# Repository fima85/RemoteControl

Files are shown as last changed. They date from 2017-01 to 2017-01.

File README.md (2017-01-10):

# RemoteControl
This application allows the user to control an electric whell chair via bluetooth.

Included, you can find the 3D model for the joystick adapter and instructions on how to print it and the schematic for the electronic circuit (and a shopping list!).
Our original usecase was for a disabled young man, who wanted to be able to send his chair away from his bed when visitors came, and call it back once they left.

Turns out that when life takes some independence from you, the best think you can do for someone, is give it back to him.

If YOU build it, it WILL come!

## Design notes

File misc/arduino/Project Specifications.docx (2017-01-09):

Project Specifications: Chair Call

System Requirements:

Close Range Remote Control System for controlling wheelchair in a room.

System should be removable. Simple attachment and detachment.

Nurse will place the device upon the wheelchair.

Parts:

Main Frame:

A main unit will fit upon the joystick. The main unit has holes for wiring, and 3* M3 holes for securing the servo holder to the Main Frame.

The frame is built to fit tightly in 3 directions around the joystick housing.

Servo Holder:

The servo holder will attach to the main unit, with M3 bolts.

The servo holder is built for two standard size servo motors

It includes a switch and a charge port.

Ring:

A ring will attach to the joystick, padded with rubber for a tight fit over the joystick. Internal Diameter is set to be joystick diameter + 4mm to allow padding. Prototype ring was cut from 3mm acrylic in a laser cutter. Similar results where achieved in 3d printing. The sheathing of a DVI cable was cut off, and split down the bottom. The sheathing was wrapped around the inside of the ring, and fastened with sewing string.

Connecting Rods:

Circuit:

Arduino Nano

Bluetooth Module

2*100KΩ Resistors

Mechanical Parts:

3* M3x30 Bolt

3* M3 Nuts

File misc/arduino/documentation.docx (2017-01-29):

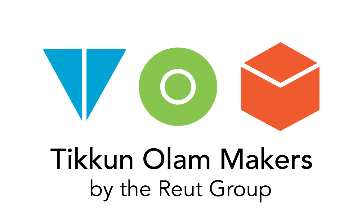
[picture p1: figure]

# Build Instructions: Chair Call

Allowing remote control over a wheel chair via Bluetooth

Developed by: Idan Timsit, Natan Vinshtok Melnik, Maor Farid, Rafael Borenstein, Effi Hagai, Fima Autenshlus, Hila Boral, Mati Gurten, Yonatan Schachter

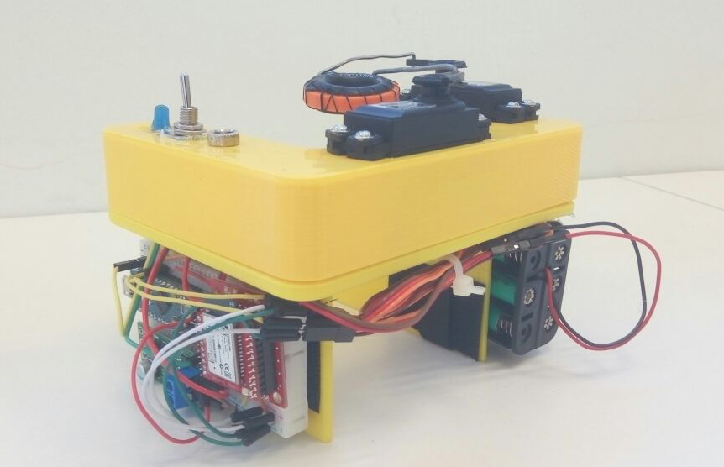
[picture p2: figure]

Approximate Cost: Insert cost

Time Required: 6 hours

# General Warnings and Cautions

- Read through entire manual before attempting to build this device.
- Do not attempt a step if you are unsure of what you are doing. Certain steps in this manual require experience with fabrication tools.

# User Assistance

For any questions regarding the assembly, operation, or specifications of this device, please visit https://github.com/fima85/remotecontrol

# Icon Glossary

The following icons may be used throughout this manual—each with its own purpose.

- Caution: The caution icon is used to signify whenever someone attempting the procedure may injure themselves or damage their equipment.
- Note: The note icon is used to signify useful bits of information that complement the instructions.
- Reminder: The reminder icon is used to provide information for after the procedure is completed, such as tips for disassembly.

# Purpose of Device:

This device allows a wheel chair user to remotely control his wheelchair. It can be very useful for some cases. For example, when the user has visitors, he might want to move the chair away from his bed.

# Physical Description:

The device consists of three parts:

1) Software: The user uses the controls in the custom app that we built. The app sends the commands via Bluetooth to the Electronics.
2) Electronics: A Bluetooth module receives the commands sent by the user. It then moves the servos accordingly.
3) Mechanical: the servos are mechanically connected to the original joystick of the wheelchair.

History of Development:

This device was developed at TOM:IL 2017.

# Bill of Materials

# Tools Required:

- 3D printer
- A computer with the Arduino software and drivers
- Hot glue
- Screwdrivers
- Soldering iron
- Pliers

# Parts Inventory:

- Click here to enter text.
- Click here to enter text.
- Click here to enter text.

[Insert image of parts]

# Subassembly 1: Title of Subassembly

[Insert image of subassembly]

Approximate Cost: Insert cost

Time Required: Insert time

# Step Number

## Parts and Tools Used In This Step:

[Insert image(s) for step]

- Click here to enter text.
- Click here to enter text.
- Click here to enter text.

[Insert image of parts and tools used]

## Instructions

- Click here to enter text.
- Click here to enter text.
- Click here to enter text.
- Click here to enter text.
- Click here to enter text.
- Click here to enter text.
- Click here to enter text.

# Step Number

## Parts and Tools Used In This Step:

[Insert image(s) for step]

- Click here to enter text.
- Click here to enter text.
- Click here to enter text.

[Insert image of parts and tools used]

## Instructions

- Click here to enter text.
- Click here to enter text.
- Click here to enter text.
- Click here to enter text.
- Click here to enter text.
- Click here to enter text.
- Click here to enter text.

# Step Number

## Parts and Tools Used In This Step:

[Insert image(s) for step]

- Click here to enter text.
- Click here to enter text.
- Click here to enter text.

[Insert image of parts and tools used]

## Instructions

- Click here to enter text.
- Click here to enter text.
- Click here to enter text.
- Click here to enter text.
- Click here to enter text.
- Click here to enter text.
- Click here to enter text.

© Tikkun Olam Makers—<<License>>www.tomglobal.orgPage 4

© Tikkun Olam Makers—<<License>>www.tomglobal.orgPage 5

© Tikkun Olam Makers—<<License>>www.tomglobal.orgPage 9

Build Instructions: Chair Call Last revised: 1/10/2017

Build Instructions: Click here to enter text. Last revised: Click here to enter a date.

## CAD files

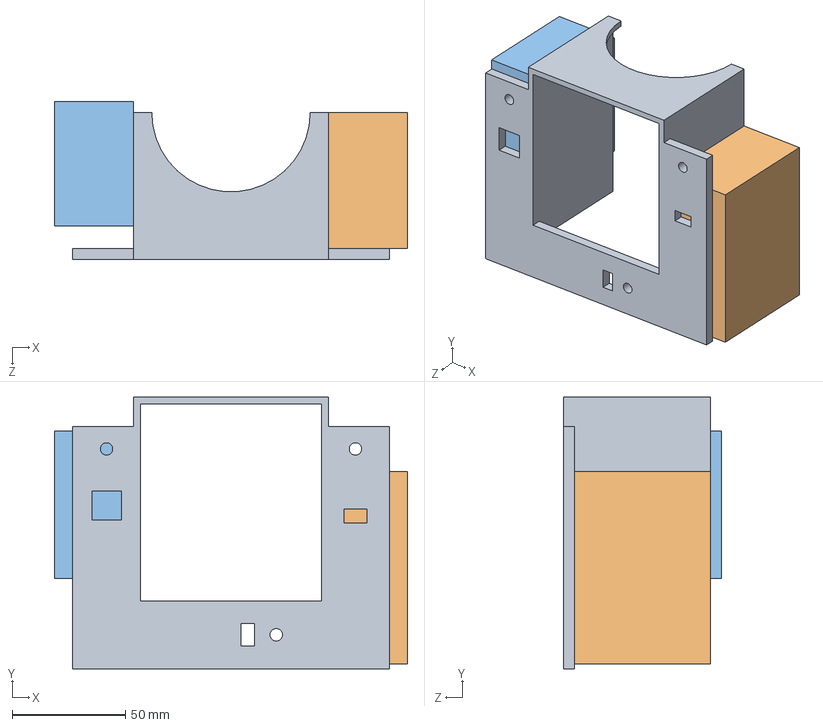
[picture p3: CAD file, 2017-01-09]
misc/ACS Joystick sketch/Assemblyjan8th925PM.SLDASM
156.0 x 120.0 x 70.0 mm
frameRev3
electronics
bataries

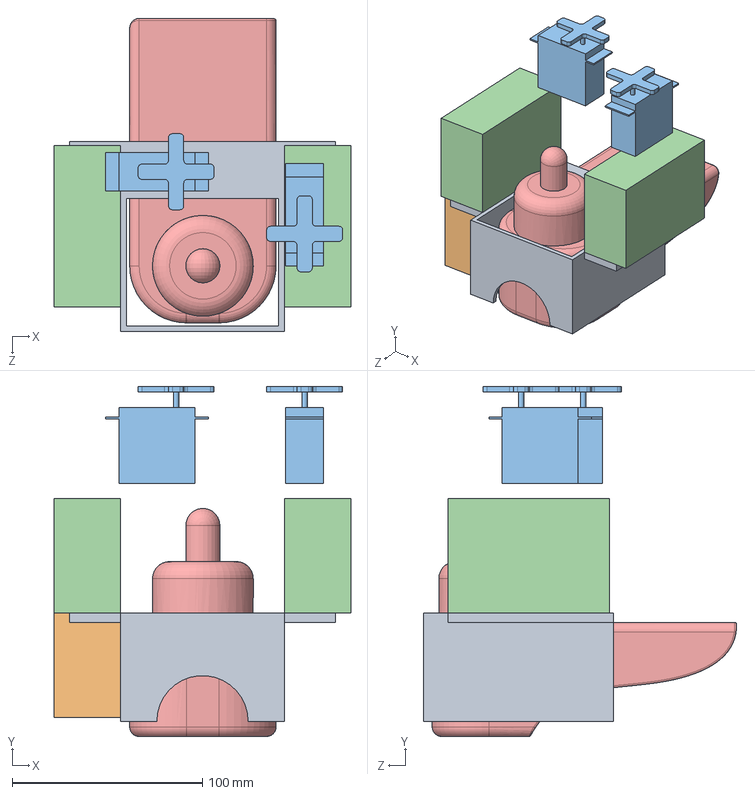
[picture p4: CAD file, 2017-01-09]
misc/ACS Joystick sketch/device_asm.SLDASM
156.0 x 184.0 x 164.6 mm
frameRev2
bataries
shoshana x 2
electronics x 2
Joystick

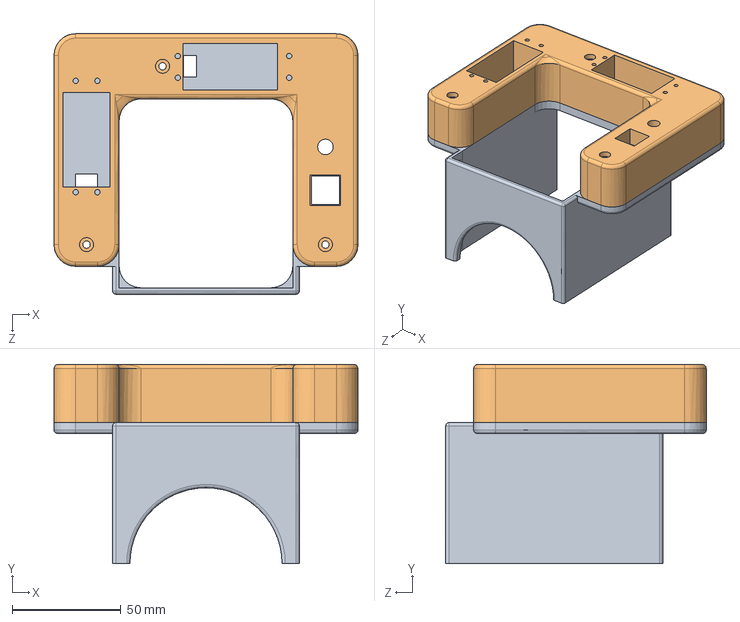
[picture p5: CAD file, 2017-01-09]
misc/ACS Joystick sketch/Assemblyjan9th103PM.SLDASM
140.0 x 91.8 x 120.0 mm
frameRev4
ServoHolderRev4

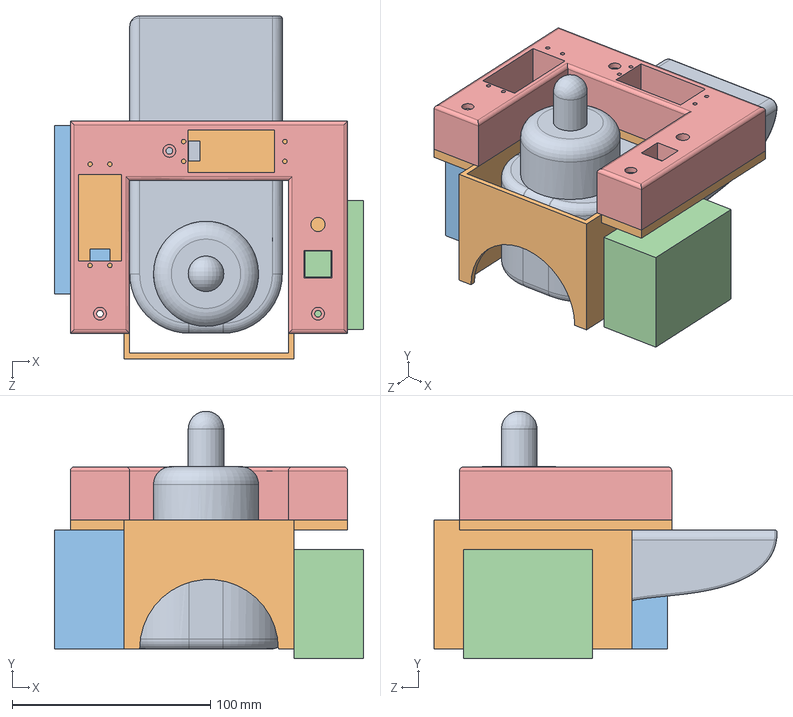
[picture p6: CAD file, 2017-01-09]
misc/ACS Joystick sketch/total_asm2.SLDASM
156.0 x 124.9 x 173.1 mm
Joystick
frameRev3
electronics
bataries
ServoHolderRev3

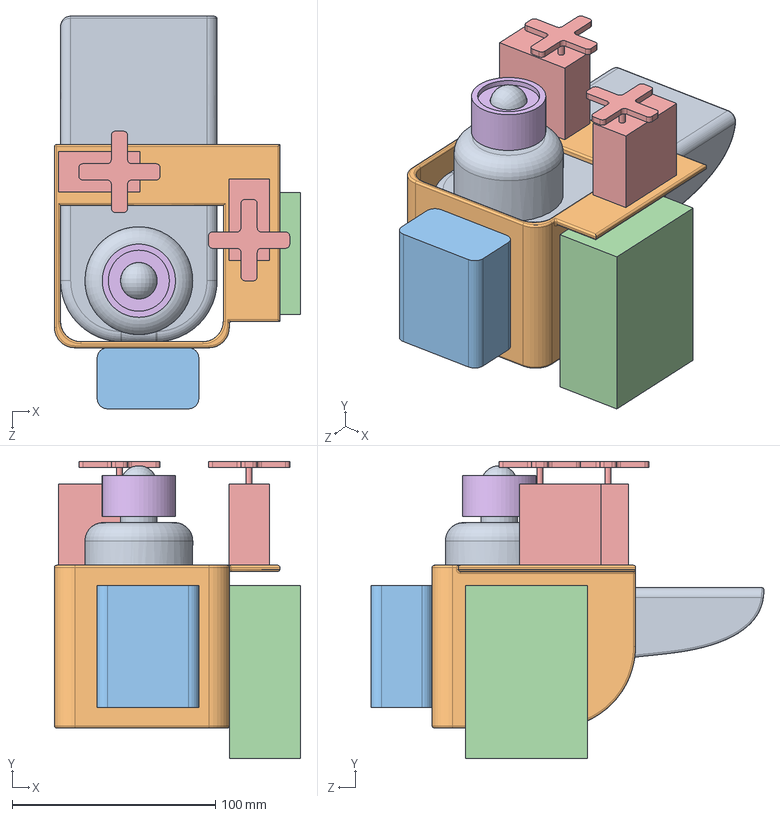
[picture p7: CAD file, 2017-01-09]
misc/ACS Joystick sketch/total_asm.SLDASM
121.0 x 146.0 x 193.1 mm
Joystick
frameRev2
bataries
electronics
shoshana x 2
gumi

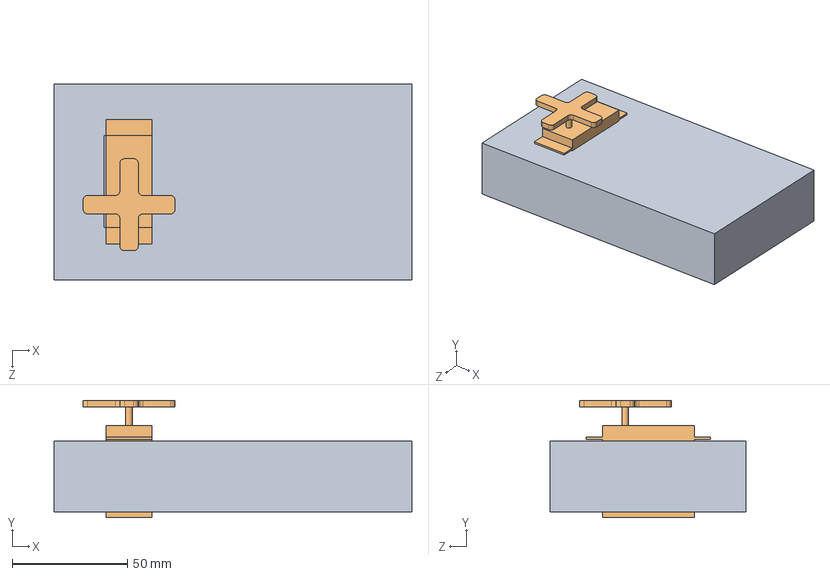
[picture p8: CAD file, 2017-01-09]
misc/ACS Joystick sketch/Assem1.SLDASM
155.5 x 51.0 x 85.3 mm
platform_test
shoshana

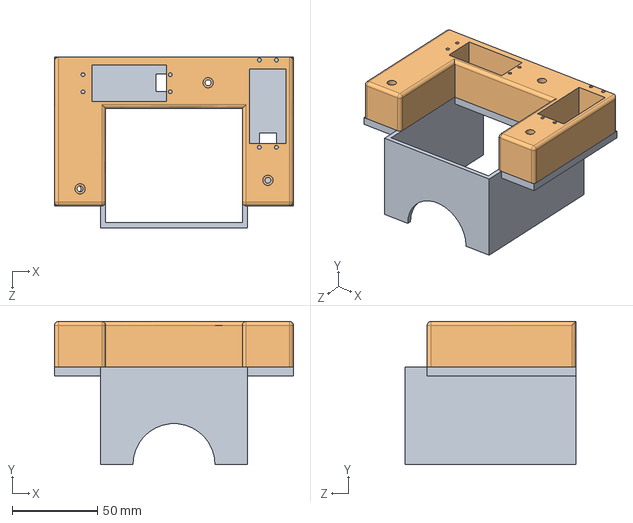
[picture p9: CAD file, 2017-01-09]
misc/ACS Joystick sketch/Assemblyjan8th743PM.SLDASM
140.0 x 83.8 x 100.0 mm
frameRev2
ServoHolderRev2

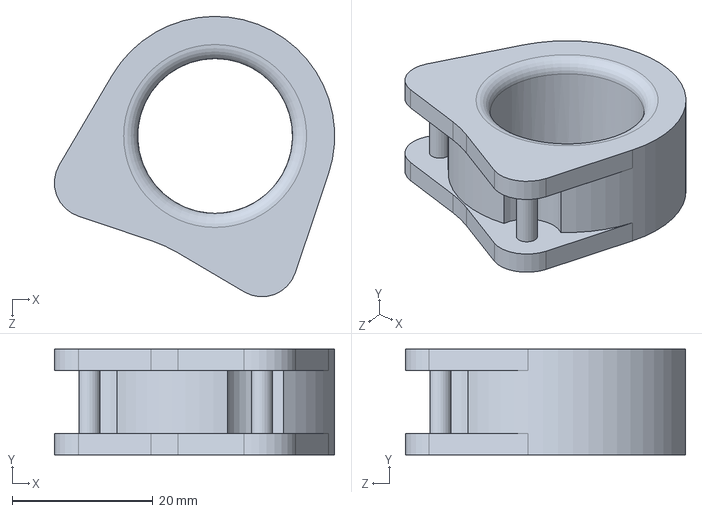
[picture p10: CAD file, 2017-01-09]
misc/ACS Joystick sketch/RingTest.SLDPRT
39.8 x 15.0 x 39.8 mm

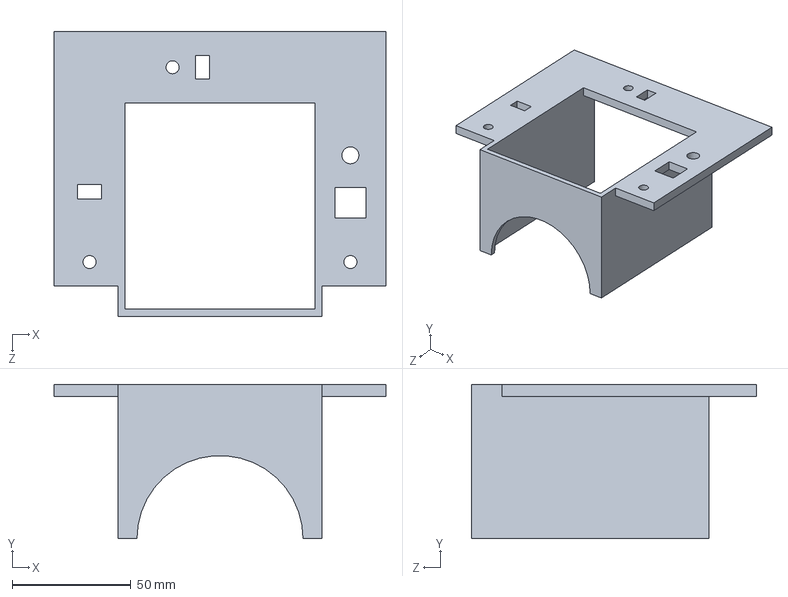
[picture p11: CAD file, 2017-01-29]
misc/arduino/frameRev4.SLDPRT
140.0 x 65.0 x 120.0 mm

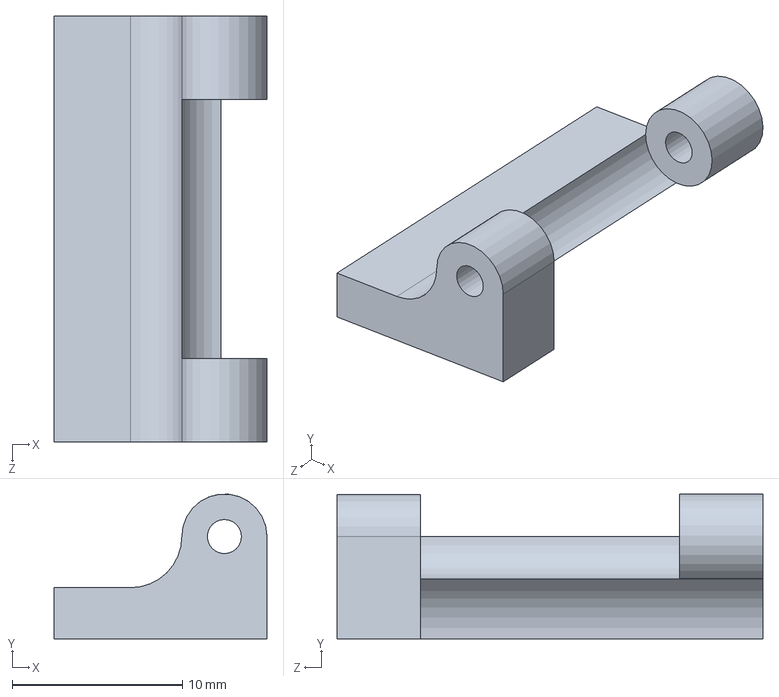
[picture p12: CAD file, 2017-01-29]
misc/arduino/battery_hinge.SLDPRT
12.5 x 8.49 x 25.0 mm

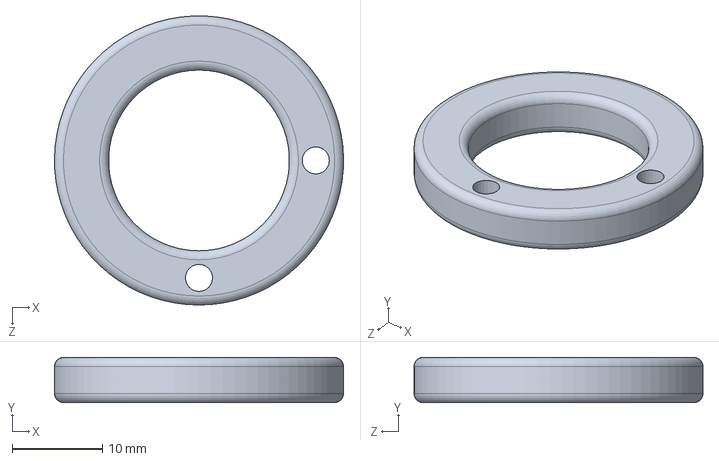
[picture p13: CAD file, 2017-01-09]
misc/ACS Joystick sketch/RingRev1.SLDPRT
32.0 x 5.00 x 32.0 mm

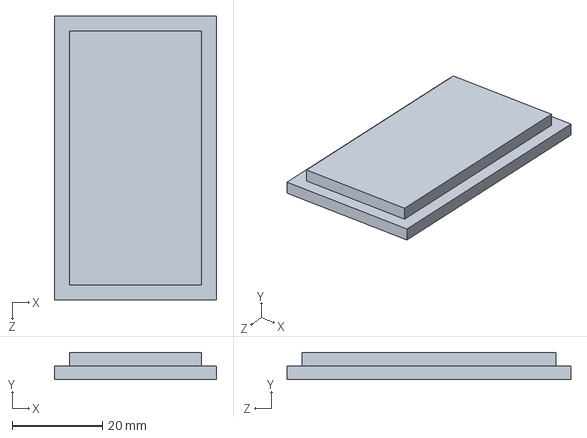
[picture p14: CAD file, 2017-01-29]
misc/arduino/covertop.SLDPRT
36.0 x 6.00 x 63.0 mm

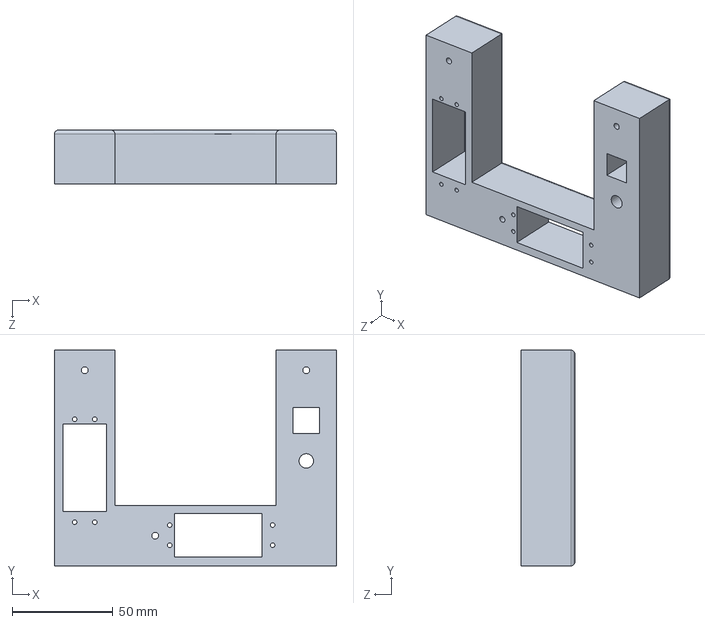
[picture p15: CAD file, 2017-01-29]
misc/arduino/ServoHolderRev4.SLDPRT
140.0 x 107.1 x 26.8 mm

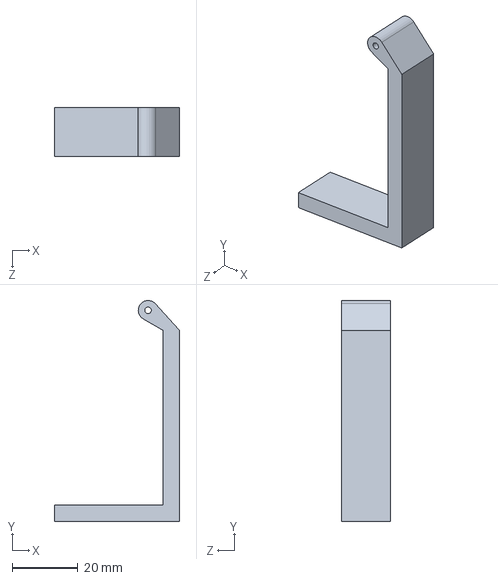
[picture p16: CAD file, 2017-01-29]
misc/arduino/battery_holder.SLDPRT
38.0 x 67.1 x 15.0 mm

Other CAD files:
misc/arduino/Assemblyjan9th103PM.SLDASM
misc/ACS Joystick sketch/frameRev4.SLDPRT
misc/arduino/RingCap.SLDPRT
misc/ACS Joystick sketch/ServoHolder.SLDPRT
misc/ACS Joystick sketch/ServoHolderRev2.SLDPRT
misc/ACS Joystick sketch/ServoHolderRev3.SLDPRT
misc/ACS Joystick sketch/ServoHolderRev3.STL
misc/ACS Joystick sketch/ServoHolderRev4.SLDPRT
misc/ACS Joystick sketch/bataries.SLDPRT
misc/ACS Joystick sketch/electronics.SLDPRT
misc/ACS Joystick sketch/frame.SLDPRT
misc/ACS Joystick sketch/frame.STL
misc/ACS Joystick sketch/frameRev2.SLDPRT
misc/ACS Joystick sketch/frameRev3.SLDPRT
misc/ACS Joystick sketch/frameRev3.STL
misc/ACS Joystick sketch/gumi.SLDPRT
misc/ACS Joystick sketch/platform_test.SLDPRT
misc/ACS Joystick sketch/shoshana.SLDPRT
misc/arduino/Joystick.SLDPRT
misc/arduino/coverbox.SLDPRT

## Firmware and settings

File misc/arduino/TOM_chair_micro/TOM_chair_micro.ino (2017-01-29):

#include <PololuMaestro.h>
#include <SoftwareSerial.h>
#include <Servo.h>

#define SAMPLE_TIME 100 //millis

#define BATT_PIN A5
#define BT_LED_PIN 4
#define LOW_BATT_PIN 11
#define THRESHOLD 580

Servo front;
Servo side;
/* Arduino micro has only 1 HW serial channel, reserved for PC and debugging */
SoftwareSerial BTserial(8,9); // rx,tx

byte commandInput='Z';
bool bluetoothLed=0; 
int commResult, drive=0, steer=0, lastSteer=1500, lastDrive=1500, voltageLevel;
unsigned long now;

void setup() {
  Serial.begin(9600);
  BTserial.begin(9600);
  BTserial.listen();
  front.attach(6); // Vertical servo signal pin
  side.attach(7); // Horizontal servo signal pin
  pinMode(BT_LED_PIN,INPUT); // In order to detect when the connection LED is blinking (=connection lost)
  pinMode(LOW_BATT_PIN, OUTPUT);// This LED will light up when battery voltage drops below 5.5V
  digitalWrite(LOW_BATT_PIN,LOW); 
  now=millis();
}

void loop() {
  if (millis()-now>=SAMPLE_TIME){
    bluetoothLed=digitalRead(BT_LED_PIN);
    voltageLevel=analogRead(BATT_PIN);    
    if (BTserial.available()>0){            
      commResult=commProtocol(&commandInput);
      if (commResult!=0){
        Serial.println(commResult);        
        while (BTserial.available()>0){
          if  (BTserial.read()=='E') {            
            break; 
          }         
        }                      
      }
      else{
        // What to do if the input packet is invalid            
      }
    }// if serial available    
    else{
      // What to do if there is nothing in the buffer            
    }// else serial available    
  
     /* The following is for when we attach the motors
      *  Angles from 0 to 180 degrees correspond to values
      *  of 1000 (0 degs) to 2000 (180 degs), in Microseconds.
      */ 
    if (bluetoothLed){
      commandInput='w';
    }
    if (voltageLevel<THRESHOLD){
      commandInput='v';
      digitalWrite(LOW_BATT_PIN,HIGH);
    }
    else{
      digitalWrite(LOW_BATT_PIN,LOW);
    }
    switch (commandInput){
      // First batch is for the "weak force" commands
      case 'a':
        drive=1500;
        steer=1500;
        break;
      case 'f':
        drive=1750;
        steer=1500;
        break;
      case 'e':
        drive=1750;
        steer=1250;
        break;
      case 'd':
        drive=1500;
        steer=1250;
        break;
      case 'c':
        drive=1250;
        steer=1250;
        break;
      case 'b':
        drive=1250;
        steer=1500;
        break;
      case 'i':
        drive=1250;
        steer=1750;
        break;
      case 'h':
        drive=1500;
        steer=1750;
        break;
      case 'g':
        drive=1750;
        steer=1750;
        break;
        
      // Second batch is for the "strong force" commands      
      case 'o':
        drive=2000;
        steer=1500;
        break;
      case 'n':
        drive=2000;
        steer=1000;
        break;
      case 'm':
        drive=1500;
        steer=1000;
        break;
      case 'l':
        drive=1000;
        steer=1000;
        break;
      case 'k':
        drive=1000;
        steer=1500;
        break;
      case 'r':
        drive=1000;
        steer=2000;
        break;
      case 'q':
        drive=1500;
        steer=2000;
        break;
      case 'p':
        drive=2000;
        steer=2000;
        break; 
      default:
        drive=1500;
        steer=1500;
        break;       
    } 

    /* The following segment negates servo jittering */
    if (steer!=lastSteer){ 
      side.writeMicroseconds(steer);      
    }
    if (drive!=lastDrive) {
      front.writeMicroseconds(drive);         
    }
        
    // Debug: 
    /*   
    Serial.print("drive: ");
    Serial.print(drive);
    Serial.print(" steer: ");
    Serial.print(steer);
    Serial.print(" command: ");
    Serial.println(char(commandInput));
    */
        
    now=millis();
    lastSteer=steer;
    lastDrive=drive;
  } //if sample time  
      
}//loop
  
int commProtocol (byte *command){ // Acceptable input in the form of: AA<command>E
  int incoming=0;
  delay(1);  
  incoming=BTserial.read();  
  if (incoming=='A'){
    incoming=BTserial.read();
    if (incoming=='A'){
      *command=BTserial.read();            
      if (BTserial.read()!='E') return(40);      
      else{        
        return(0);
      }
    }// second A
    else return(20);
  }// first A
  else return(10);
}

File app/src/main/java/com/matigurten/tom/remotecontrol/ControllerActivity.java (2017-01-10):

package com.matigurten.tom.remotecontrol;

import android.content.Intent;
import android.os.Bundle;
import android.support.v7.app.AppCompatActivity;
import android.view.Menu;
import android.view.MenuInflater;
import android.view.MenuItem;
import android.view.View;
import android.widget.ProgressBar;
import android.widget.Toast;

import com.matigurten.tom.remotecontrol.bluetooth.BLConn;
import com.matigurten.tom.remotecontrol.proxy.RemoteProxy;

public abstract class ControllerActivity extends AppCompatActivity {

    RemoteProxy remote = BLConn.getInstance();
    private Menu menu;

    @Override
    protected void onCreate(Bundle savedInstanceState) {
        super.onCreate(savedInstanceState);
        setContentView(R.layout.activity_controller);
        ProgressBar spinner = (ProgressBar) findViewById(R.id.spinner);
        spinner.setVisibility(View.GONE);

    }

    @Override
    public boolean onCreateOptionsMenu(Menu menu) {
        MenuInflater inflater = getMenuInflater();
        inflater.inflate(R.menu.main_menu, menu);
        this.menu = menu;
        menu.findItem(R.id.connect).setEnabled(!BLConn.getInstance().isConnected());
        menu.findItem(R.id.connect).setVisible(!BLConn.getInstance().isConnected());

        menu.findItem(R.id.disconnect).setEnabled(BLConn.getInstance().isConnected());
        menu.findItem(R.id.disconnect).setVisible(BLConn.getInstance().isConnected());
        return true;
    }

    @Override
    public boolean onOptionsItemSelected(final MenuItem item) {
        // Handle action bar item clicks here. The action bar will
        // automatically handle clicks on the Home/Up button, so long
        // as you specify a parent activity in AndroidManifest.xml.
        int id = item.getItemId();
        if (id == R.id.activity_settings) {
            startActivity(new Intent(getApplicationContext(), SettingsActivity.class));
            return true;
        } else if (id == R.id.app_about) {
            startActivity(new Intent(getApplicationContext(), AboutActivity.class));
            return true;
        } else if (id == R.id.connect) {

            BLConn.getInstance().connect(getApplicationContext(), new BLConn.BLUpdateCallback() {
                @Override
                public void onConnect(boolean success) {
                    runOnUiThread(new Runnable() {
                                      @Override
                                      public void run() {
                                          if (BLConn.getInstance().isConnected()) {
                                              item.setVisible(false);
                                              item.setEnabled(false);
                                              menu.findItem(R.id.disconnect).setEnabled(true);
                                              menu.findItem(R.id.disconnect).setVisible(true);
//                                              if(this instanceof RemoteControlActivity) {
//                                                  spinner.setVisibility(View.GONE);
//                                              }
                                              Toast.makeText(getApplicationContext(), "Connected", Toast.LENGTH_LONG).show();
                                          } else {
//                                              spinner.setVisibility(View.GONE);
                                              Toast.makeText(getApplicationContext(), "Failed to connect", Toast.LENGTH_LONG).show();
                                          }
                                      }
                                  }
                    );
                }
            });
        } else if (id == R.id.disconnect) {
            BLConn.getInstance().disconnect();

            item.setVisible(false);
            item.setEnabled(false);

            menu.findItem(R.id.connect).setEnabled(true);
            menu.findItem(R.id.connect).setVisible(true);
        }
        return super.onOptionsItemSelected(item);
    }

    public void flButtonOnClick(View v) {
        remote.fl(false);
    }

    public void fButtonOnClick(View v) {
        remote.f(false);
    }

    public void frButtonOnClick(View v) {
        remote.fr(false);
    }

    public void lButtonOnClick(View v) {
        remote.l(false);
    }

    public void stopButtonOnClick(View v) {
        remote.stop();
    }

    public void rButtonOnClick(View v) {
        remote.r(false);
    }

    public void blButtonOnClick(View v) {
        remote.bl(false);
    }

    public void bButtonOnClick(View v) {
        remote.b(false);
    }

    public void brButtonOnClick(View v) {
        remote.br(false);
    }

    public void pflButtonOnClick(View v) {
        remote.fl(true);
    }

    public void pfButtonOnClick(View v) {
        remote.f(true);
    }

    public void pfrButtonOnClick(View v) {
        remote.fr(true);
    }

    public void plButtonOnClick(View v) {
        remote.l(true);
    }

    public void pstopButtonOnClick(View v) {
        remote.stop();
    }

    public void prButtonOnClick(View v) {
        remote.r(true);
    }

    public void pblButtonOnClick(View v) {
        remote.bl(true);
    }

    public void pbButtonOnClick(View v) {
        remote.b(true);
    }

    public void pbrButtonOnClick(View v) {
        remote.br(true);
    }

    @Override
    public void onBackPressed() {
        return;
    }
}

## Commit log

2017-01-09 BT Update freq fix
    [encoding.xlsx]
2017-01-09 add sketches
    [Assem1.SLDASM, Assemblyjan8th743PM.SLDASM, Assemblyjan8th925PM.SLDASM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]
2017-01-09 About Activity
    [app_about.xml]
2017-01-09 More Fixes
    [app_about.xml]
2017-01-29 add arduino files
    [Assemblyjan9th103PM.SLDASM, Joystick.SLDPRT, RingCap.SLDPRT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]
